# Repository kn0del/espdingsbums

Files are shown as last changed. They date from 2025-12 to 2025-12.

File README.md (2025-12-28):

# Zustand
--

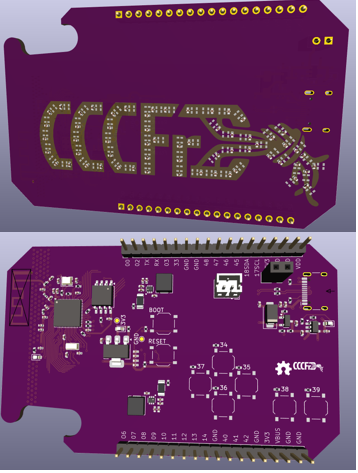
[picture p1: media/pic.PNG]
Board


**integrated bottle opener
one time use only**

Form Faktor: Kreditkarte/Perso?

- ESP32-S3 
- Antenne 
- Xtal 
- Voltage regulator 
- USB-C stecker 
- Li-Po Batteriencharger 
- Einige basic Tasten z.B RESET 
- Pin headers (vielleicht muss weg)
- LEDs an der Rückseite
- Mehrere Tasten (6)
- Flaschenöffner

# to-do liste
- ESD protection?
- Bildschirm an der Rückseite?
- Accelerometer?
- Noch was?

--

# Anleitung / Instructions

## DE

- Normallerweise sollte PlatformIO das Board als USB-Gerät erkennen.  
- Du brauchst keinen USB/UART-IC, z.B. CH340.  
- Der SoC hat diese Funktion bereits integriert.
- Die LEDs (XL-1615RGBC-2812B) sind eine Kleinformatversion der Standard WS2812B LEDs.Die nutzen einen digitalen Input-Pin (GPIO 21) und funktionieren wie jeder WS2812B LED strip. Theoretisch könntest du am Ende noch mehr einbauen, aber irgendwann wird dann zu viel Strom gebraucht.
- Die Reihenfolge der LEDs im Logo geht von oben nach unten und dann von links nach rechts auf einem quasi-Pixelraster, nicht von Buchstabe zu Buchstabe.
- LEDs verwenden ihre eigene 5V rail, die aktiviert werden muss, indem die Logik auf GPIO5 auf „high“ gesetzt wird.
- Die Reset- und Boot-Tasten haben eine bestimmte Funktion, aber die nummerierten Tasten sind nur dazu da, um programmiert zu werden. Sie sind standardmäßig alle auf „high“ gesetzt und werden durch Drücken der Taste auf „ground“ gesetzt.

**Wenn die Firmware kaputt geht:**  
- PlatformIO erkennt das Devboard nicht als USB-Gerät.  
- In diesem Fall: Halte die Boot-Taste (GPIO0) gedrückt und tippe auf Reset (EN).  
- Damit wird der Chip in den Download-Modus versetzt, und du kannst neue Firmware flashen.

---

## EN

- By default, PlatformIO should recognise the board as a USB device.  
- You don't need a USB/UART IC like CH340.  
- The SoC already has this function built in. 
- The LEDs (XL-1615RGBC-2812B) are a small package version of standard WS2812B LEDs, these use a digital input pin (GPIO 21) and work like any WS2812B strip. You can in theory add more at the end but at some point they would need too much current.
- The order of the LEDs in the logo go  top-down then left-right on a quasi pixel grid not letter by letter.
- LEDs use their own power rail that needs to be enabled by setting logic high on GPIO5
- Reset and Boot buttons have a specific function but the numbered ones are just there to be proggrammed. They are all pulled up by default and button press pulls them down to ground.

**If the firmware gets broken:**  
- PlatformIO does not recognise the devboard as a USB device.  
- In that case: hold the boot button (GPIO0) and tap reset (EN).  
- This will set the chip to download mode, and you can flash new firmware.

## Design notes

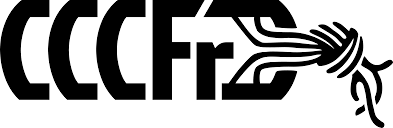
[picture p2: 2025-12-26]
media/Untitled.png

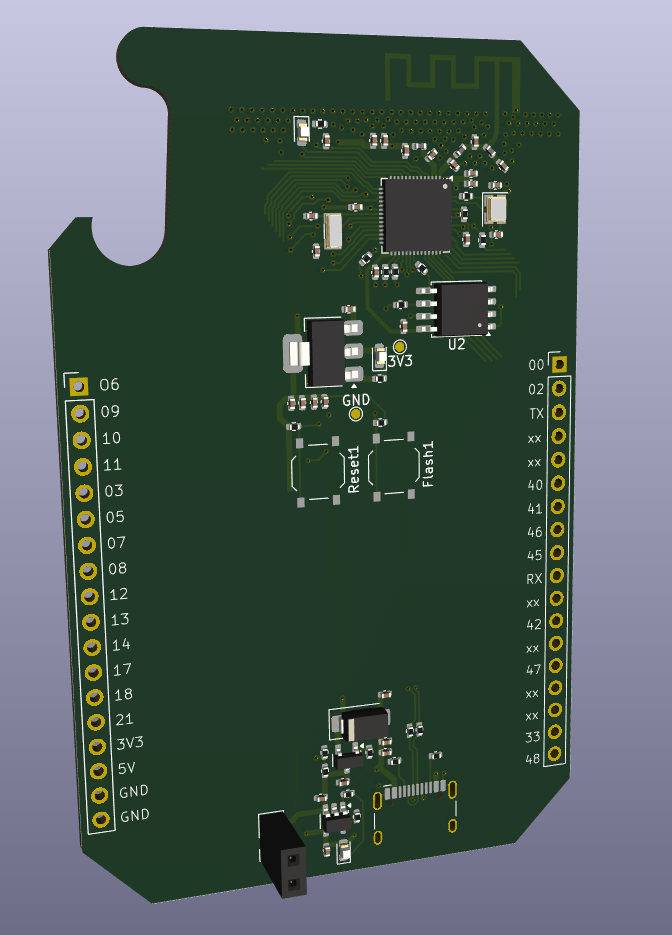
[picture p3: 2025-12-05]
media/pic - Copy.PNG

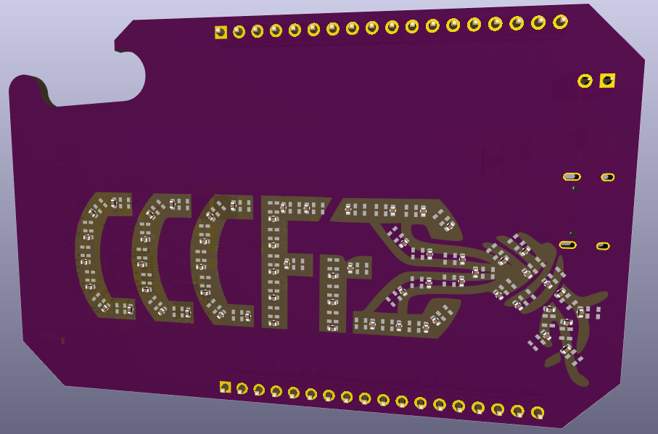
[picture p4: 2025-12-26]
media/pic - Copy (2).PNG

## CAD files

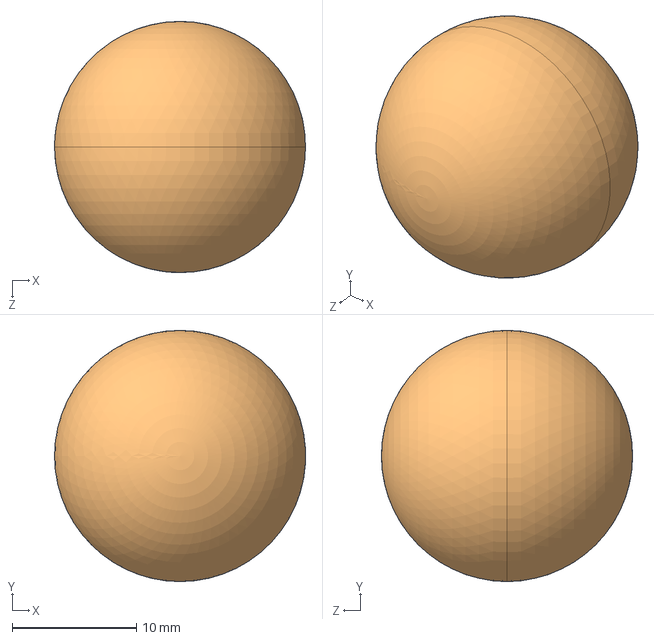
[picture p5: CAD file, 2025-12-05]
solid/original_esp32_module_antenna.STEP
20.2 x 20.3 x 20.3 mm

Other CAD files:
solid/original_esp32_module_antenna.SLDPRT

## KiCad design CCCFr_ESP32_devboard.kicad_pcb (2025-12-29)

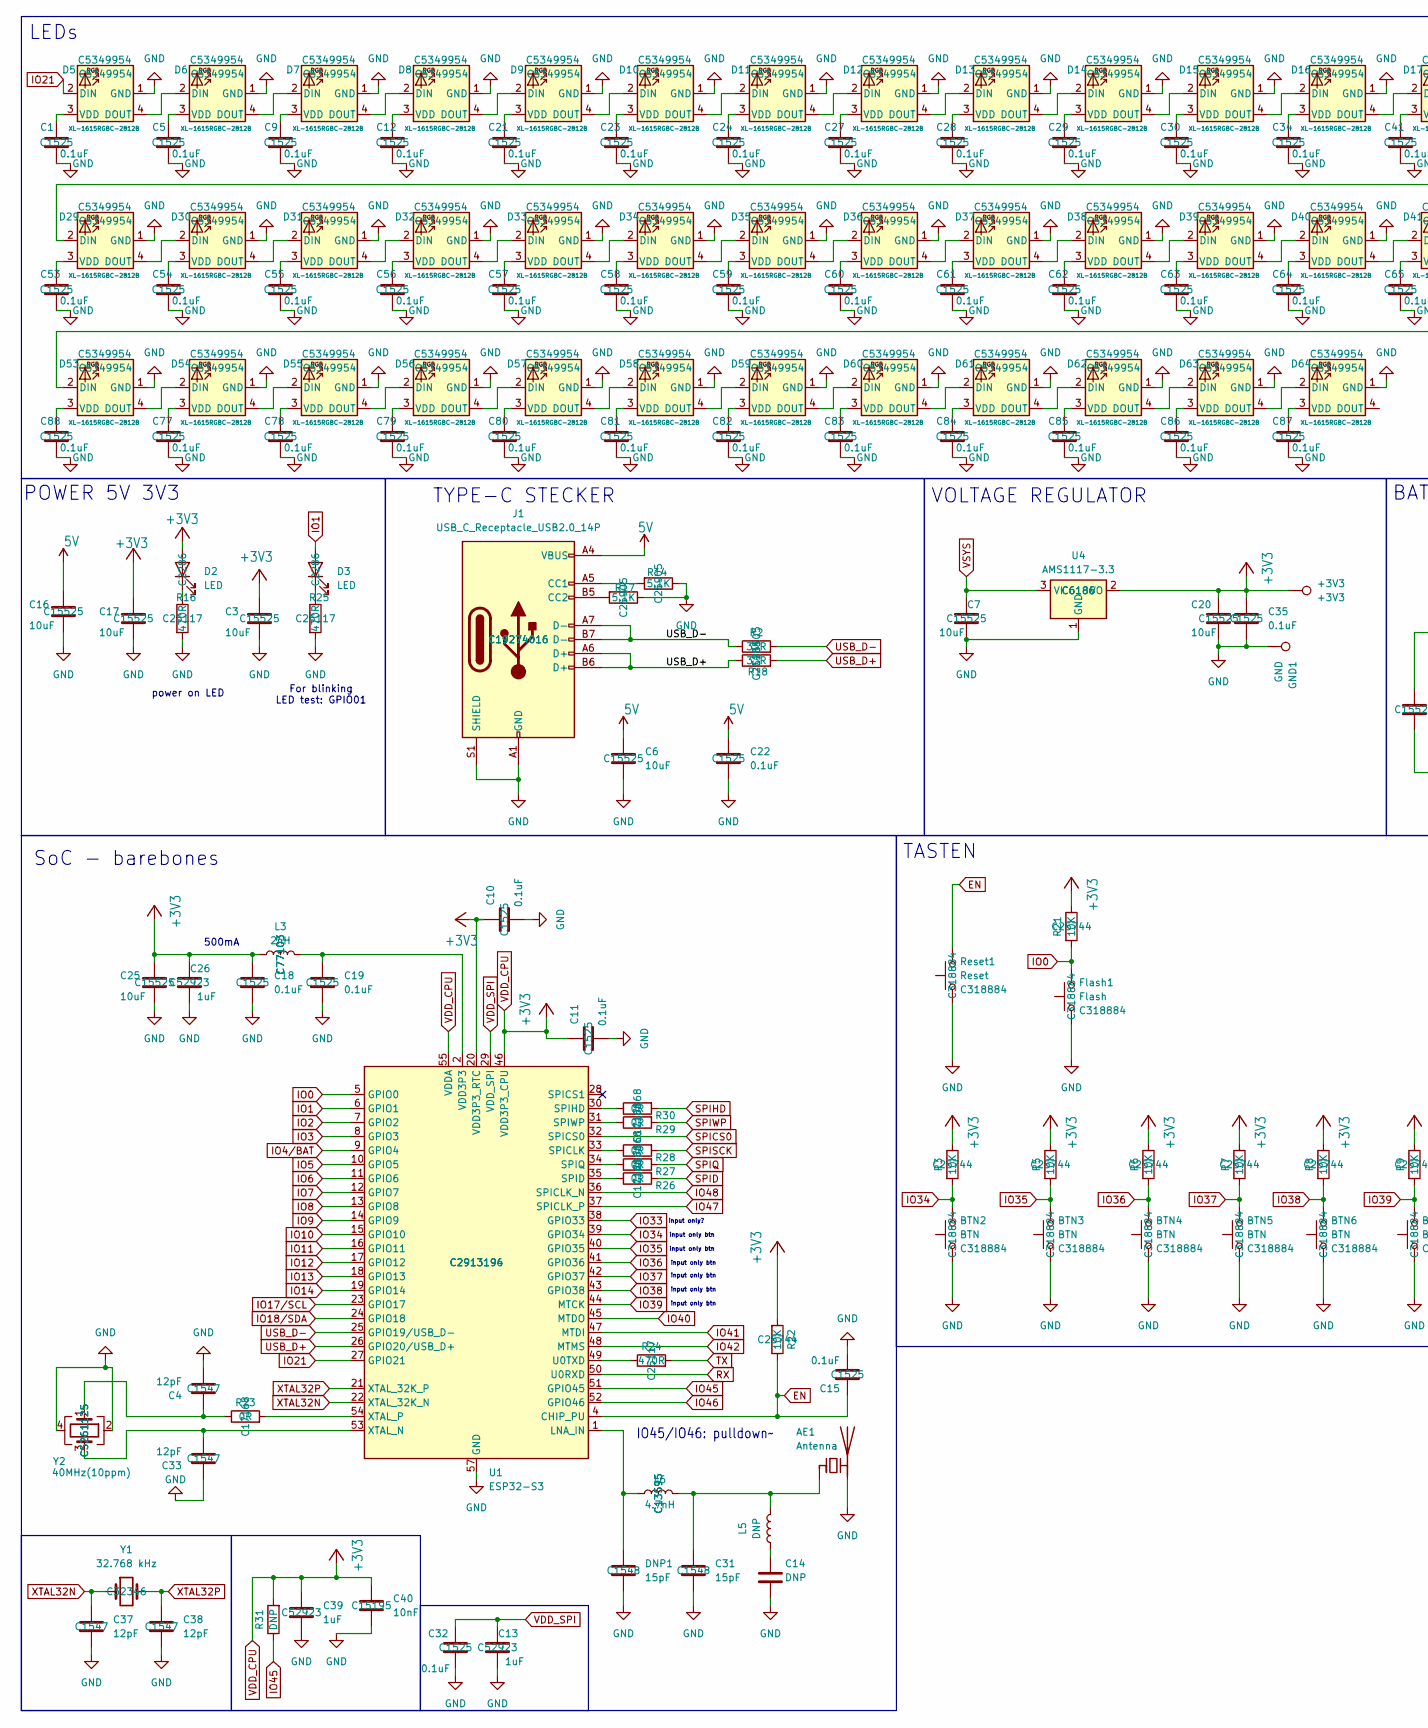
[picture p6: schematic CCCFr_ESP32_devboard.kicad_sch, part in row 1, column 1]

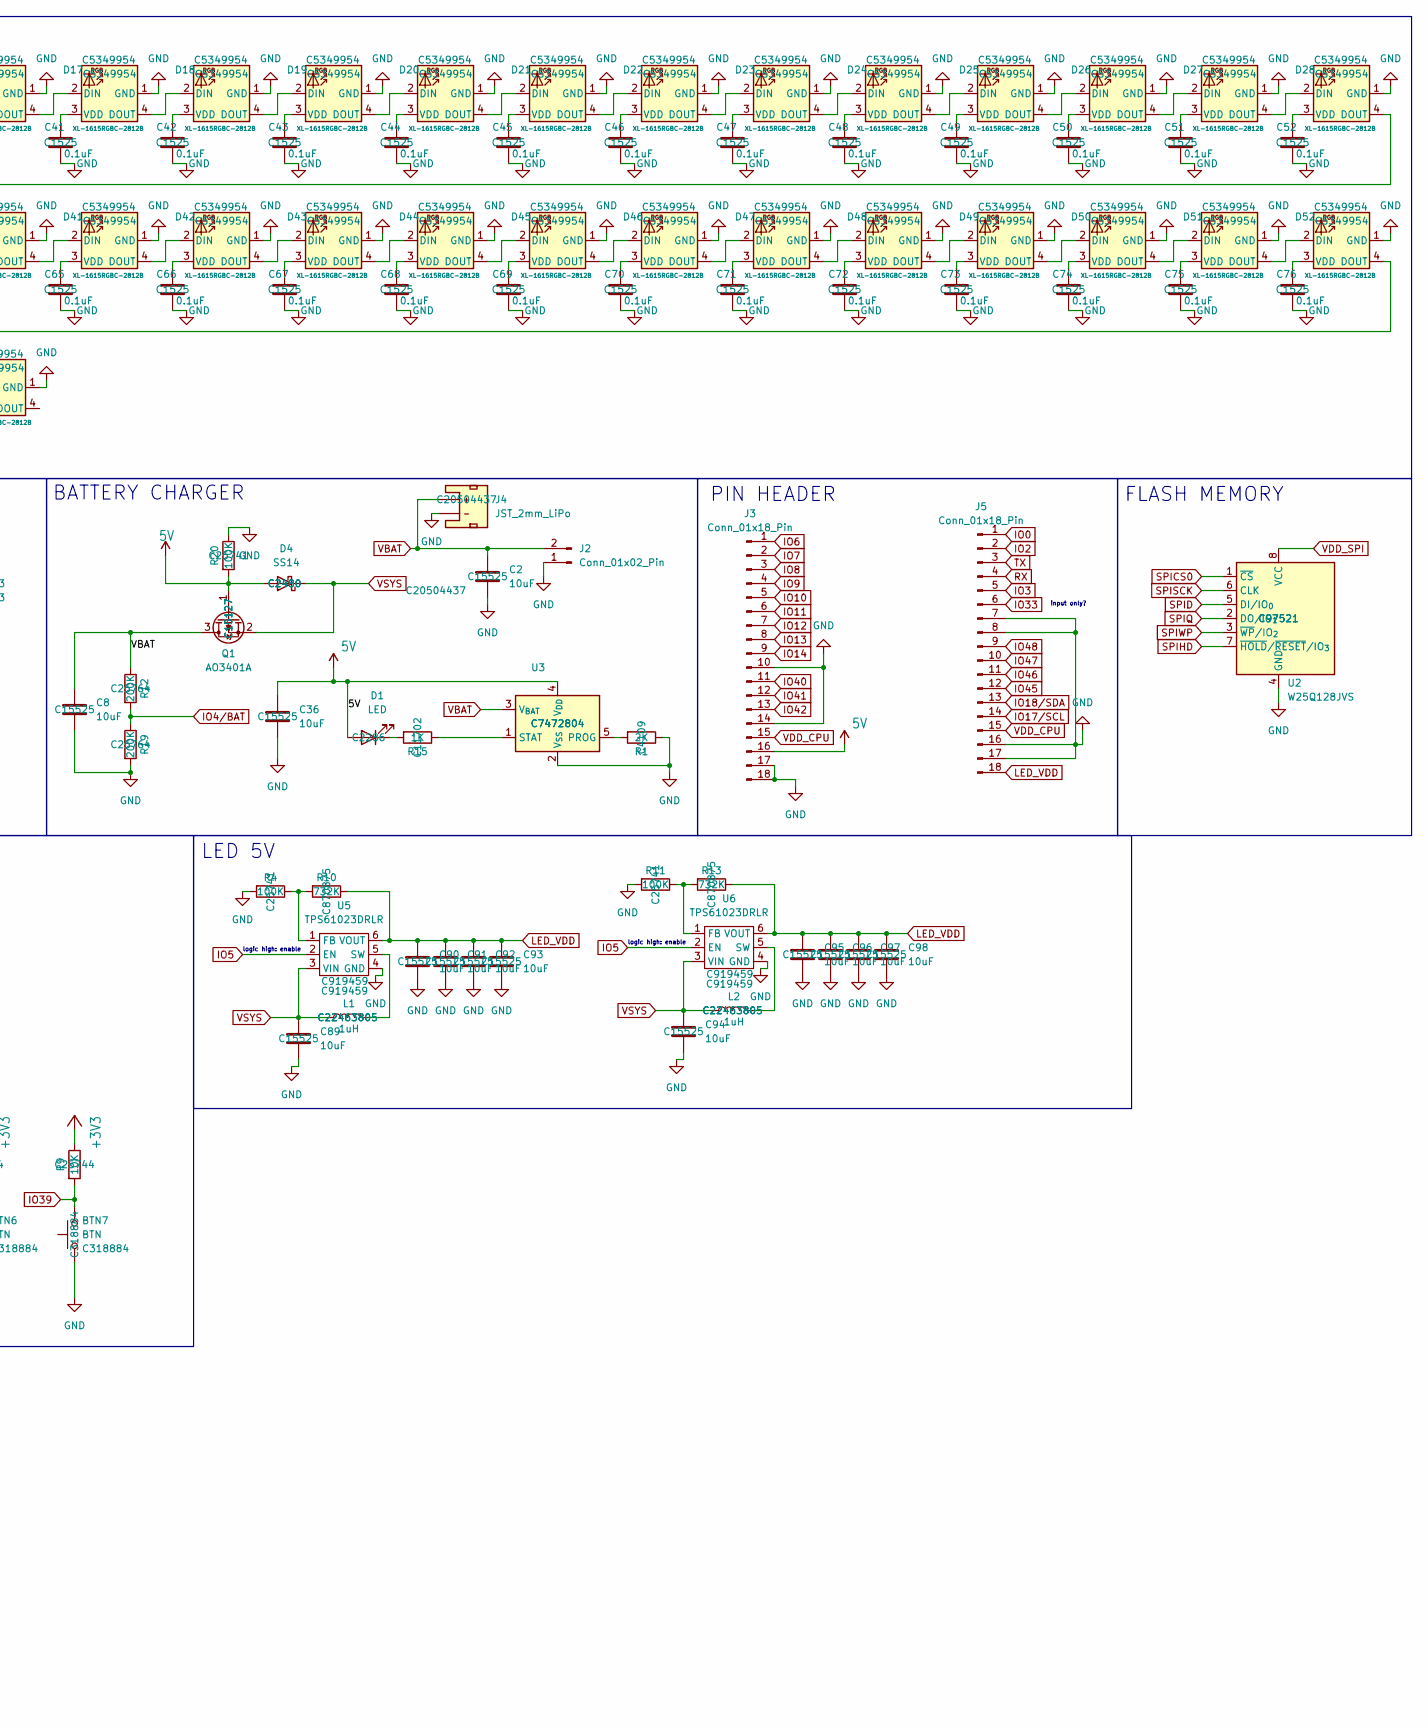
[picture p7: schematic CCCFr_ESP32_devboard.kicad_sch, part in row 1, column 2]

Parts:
+3V3: +3V3; TestPoint_Pad_D1.0mm
AE1: Antenna; Texas_SWRA117D_2.4GHz_Left
BTN2, BTN3, BTN4, BTN5, BTN6, BTN7: BTN; SW_Push_1P1T_XKB_TS-1187A; MNF PART NUMBER C318884; LCSC C318884
C1, C5, C9, C10, C11, C12, C15, C18, C19, C21, C22, C23, C24, C27, C28, C29, C30, C32, C34, C35, C41, C42, C43, C44, C45, C46, C47, C48, C49, C50, C51, C52, C53, C54, C55, C56, C57, C58, C59, C60, C61, C62, C63, C64, C65, C66, C67, C68, C69, C70, C71, C72, C73, C74, C75, C76, C77, C78, C79, C80, C81, C82, C83, C84, C85, C86, C87, C88: 0.1uF; C_0402_1005Metric; MNF PART NUMBER C1525; LCSC C1525
C2, C3, C6, C7, C8, C16, C17, C20, C25, C36, C89, C90, C91, C92, C93, C94, C95, C96, C97, C98: 10uF; C_0402_1005Metric; MNF PART NUMBER C15525; LCSC C15525
C4, C33, C37, C38: 12pF; C_0402_1005Metric; MNF PART NUMBER C1547; LCSC C1547
C13, C26, C39: 1uF; C_0402_1005Metric; MNF PART NUMBER C52923; LCSC C52923
C14: DNP; C_0402_1005Metric
C31: 15pF; C_0402_1005Metric; MNF PART NUMBER C1548; LCSC C1548
C40: 10nF; C_0402_1005Metric; MNF PART NUMBER C15195; LCSC C15195
D1, D2, D3: LED; LED_0603_1608Metric; MNF PART NUMBER C2286; LCSC C2286
D4: SS14; D_SMA; MNF PART NUMBER C2480; LCSC C2480
D5, D6, D7, D8, D9, D10, D11, D12, D13, D14, D15, D16, D17, D18, D19, D20, D21, D22, D23, D24, D25, D26, D27, D28, D29, D30, D31, D32, D33, D34, D35, D36, D37, D38, D39, D40, D41, D42, D43, D44, D45, D46, D47, D48, D49, D50, D51, D52, D53, D54, D55, D56, D57, D58, D59, D60, D61, D62, D63, D64: XL-1615RGBC-2812B; MNF PART NUMBER C5349954; LCSC C5349954
DNP1: 15pF; C_0402_1005Metric; MNF PART NUMBER C1548; LCSC C1548
Flash1: Flash; SW_Push_1P1T_XKB_TS-1187A; MNF PART NUMBER C318884; LCSC C318884
GND1: GND; TestPoint_Pad_D1.0mm
J1: USB_C_Receptacle_USB2.0_14P; USB_C_Receptacle_HCTL_HC-TYPE-C-16P-01A; MNF PART NUMBER C19274016; LCSC C19274016
J2: Conn_01x02_Pin; PinSocket_1x02_P2.54mm_Vertical
J3, J5: Conn_01x18_Pin; PinHeader_1x18_P2.54mm_Vertical
J4: JST_2mm_LiPo; JST_PH_B2B-PH-K_1x02_P2.00mm_Vertical; MNF PART NUMBER C20504437; LCSC C20504437
L1, L2: 1uH; L_TechFuse_SL0420; MNF PART NUMBER C22463805; LCSC C22463805
L3: 2nH; L_0402_1005Metric; MNF PART NUMBER C77103; LCSC C77103
L5: DNP; L_0402_1005Metric
L6: 4.7nH; L_0402_1005Metric; MNF PART NUMBER C13595; LCSC C13595
Q1: AO3401A; SOT-23; MNF PART NUMBER C15127; LCSC C15127
R1: 2K; R_0402_1005Metric; MNF PART NUMBER C4109; LCSC C4109
R2, R18: 33R; R_0402_1005Metric; MNF PART NUMBER C25105; LCSC C25105
R3, R5, R6, R7, R8, R9, R21, R22: 10K; R_0402_1005Metric; MNF PART NUMBER C25744; LCSC C25744
R4, R11, R20: 100K; R_0402_1005Metric; MNF PART NUMBER C25741; LCSC C25741
R10, R13: 732K; R_1206_3216Metric; MNF PART NUMBER C870875; LCSC C870875
R12, R19: 200K; R_0402_1005Metric; MNF PART NUMBER C25764; LCSC C25764
R14, R17: 5.1K; R_0402_1005Metric; MNF PART NUMBER C25905; LCSC C25905
R15: 1K; R_0402_1005Metric; MNF PART NUMBER C11702; LCSC C11702
R16, R24, R25: 470R; R_0402_1005Metric; MNF PART NUMBER C25117; LCSC C25117
R23, R26, R27, R28, R29, R30: 0R; R_0402_1005Metric; MNF PART NUMBER C17168; LCSC C17168
R31: DNP; R_0402_1005Metric
Reset1: Reset; SW_Push_1P1T_XKB_TS-1187A; MNF PART NUMBER C318884; LCSC C318884
U1: ESP32-S3; QFN-56-1EP_7x7mm_P0.4mm_EP4x4mm; MNF PART NUMBER C2913196; LCSC C2913194
U2: W25Q128JVS; SOIC-8_5.3x5.3mm_P1.27mm; MNF PART NUMBER C97521; LCSC C97521
U3: MCP73831-2-OT; SOT-23-5; MNF PART NUMBER C7472804; LCSC C7472804
U4: AMS1117-3.3; SOT-223-3_TabPin2; MNF PART NUMBER C6186; LCSC C6186
U5, U6: TPS61023DRLR; SOT-563; MNF PART NUMBER C919459; LCSC C919459
Y1: 32.768 kHz; Crystal_SMD_3215-2Pin_3.2x1.5mm; MNF PART NUMBER C32346; LCSC C32346
Y2: 40MHz(10ppm); Crystal_SMD_2520-4Pin_2.5x2.0mm; MNF PART NUMBER C5261125; LCSC C5261125

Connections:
5V: C6.1, C16.1, C22.1, C36.1, D1.2 (A), D4.2 (A), J1.A4 (VBUS), J1.A9 (VBUS), J1.B4 (VBUS), J1.B9 (VBUS), J3.16, Q1.1 (G), R20.2, U3.4 (V_{DD})
EN: C15.1, R22.1, Reset1.2, U1.4 (CHIP_PU)
GND: AE1.2 (PCB_Trace), BTN2.1, BTN3.1, BTN4.1, BTN5.1, BTN6.1, BTN7.1, C1.2, C2.2, C3.2, C4.2, C5.2, C6.2, C7.2, C8.2, C9.2, C10.2, C11.2, C12.2, C13.2, C14.2, C15.2, C16.2, C17.2, C18.2, C19.2, C20.2, C21.2, C22.2, C23.2, C24.2, C25.2, C26.2, C27.2, C28.2, C29.2, C30.2, C31.2, C32.2, C33.1, C34.2, C35.2, C36.2, C37.2, C38.2, C39.2, C40.2, C41.2, C42.2, C43.2, C44.2, C45.2, C46.2, C47.2, C48.2, C49.2, C50.2, C51.2, C52.2, C53.2, C54.2, C55.2, C56.2, C57.2, C58.2, C59.2, C60.2, C61.2, C62.2, C63.2, C64.2, C65.2, C66.2, C67.2, C68.2, C69.2, C70.2, C71.2, C72.2, C73.2, C74.2, C75.2, C76.2, C77.2, C78.2, C79.2, C80.2, C81.2, C82.2, C83.2, C84.2, C85.2, C86.2, C87.2, C88.2, C89.2, C90.2, C91.2, C92.2, C93.2, C94.2, C95.2, C96.2, C97.2, C98.2, D5.1 (GND), D6.1 (GND), D7.1 (GND), D8.1 (GND), D9.1 (GND), D10.1 (GND), D11.1 (GND), D12.1 (GND), D13.1 (GND), D14.1 (GND), D15.1 (GND), D16.1 (GND), D17.1 (GND), D18.1 (GND), D19.1 (GND), D20.1 (GND), D21.1 (GND), D22.1 (GND), D23.1 (GND), D24.1 (GND), D25.1 (GND), D26.1 (GND), D27.1 (GND), D28.1 (GND), D29.1 (GND), D30.1 (GND), D31.1 (GND), D32.1 (GND), D33.1 (GND), D34.1 (GND), D35.1 (GND), D36.1 (GND), D37.1 (GND), D38.1 (GND), D39.1 (GND), D40.1 (GND), D41.1 (GND), D42.1 (GND), D43.1 (GND), D44.1 (GND), D45.1 (GND), D46.1 (GND), D47.1 (GND), D48.1 (GND), D49.1 (GND), D50.1 (GND), D51.1 (GND), D52.1 (GND), D53.1 (GND), D54.1 (GND), D55.1 (GND), D56.1 (GND), D57.1 (GND), D58.1 (GND), D59.1 (GND), D60.1 (GND), D61.1 (GND), D62.1 (GND), D63.1 (GND), D64.1 (GND), DNP1.2, Flash1.1, GND1.1, J1.A1 (GND), J1.A12 (GND), J1.B1 (GND), J1.B12 (GND), J1.S1 (SHIELD), J2.1, J3.10, J3.14, J3.17, J3.18, J4.1 (-), J5.7, J5.8, J5.16, J5.17, R1.1, R4.2, R11.2, R14.1, R16.2, R17.1, R19.2, R20.1, R25.2, Reset1.1, U1.57 (GND), U2.4 (GND), U3.2 (V_{SS}), U4.1 (GND), U5.4 (GND), U6.4 (GND), Y2.2, Y2.4
IO0: Flash1.2, J5.1, R21.2, U1.5 (GPIO0)
IO1: D3.2 (A), U1.6 (GPIO1)
IO2: J5.2, U1.7 (GPIO2)
IO3: J5.5, U1.8 (GPIO3)
IO4/BAT: R12.2, R19.1, U1.9 (GPIO4)
IO5: U1.10 (GPIO5), U5.2 (EN), U6.2 (EN)
IO6: J3.1, U1.11 (GPIO6)
IO7: J3.2, U1.12 (GPIO7)
IO8: J3.3, U1.13 (GPIO8)
IO9: J3.4, U1.14 (GPIO9)
IO10: J3.5, U1.15 (GPIO10)
IO11: J3.6, U1.16 (GPIO11)
IO12: J3.7, U1.17 (GPIO12)
IO13: J3.8, U1.18 (GPIO13)
IO14: J3.9, U1.19 (GPIO14)
IO17/SCL: J5.14, U1.23 (GPIO17)
IO18/SDA: J5.13, U1.24 (GPIO18)
IO21: D5.2 (DIN), U1.27 (GPIO21)
IO33: J5.6, U1.38 (GPIO33)
IO34: BTN2.2, R3.2, U1.39 (GPIO34)
IO35: BTN3.2, R5.2, U1.40 (GPIO35)
IO36: BTN4.2, R6.2, U1.41 (GPIO36)
IO37: BTN5.2, R7.2, U1.42 (GPIO37)
IO38: BTN6.2, R8.2, U1.43 (GPIO38)
IO39: BTN7.2, R9.2, U1.44 (MTCK)
IO40: J3.11, U1.45 (MTDO)
IO41: J3.12, U1.47 (MTDI)
IO42: J3.13, U1.48 (MTMS)
IO45: J5.12, R31.1, U1.51 (GPIO45)
IO46: J5.11, U1.52 (GPIO46)
IO47: J5.10, U1.37 (SPICLK_P)
IO48: J5.9, U1.36 (SPICLK_N)
LED_VDD: C90.1, C91.1, C92.1, C93.1, C95.1, C96.1, C97.1, C98.1, J5.18, R10.1, R13.1, U5.6 (VOUT), U6.6 (VOUT)
unnamed: AE1.1 (FEED), C31.1, L5.2, L6.2
unnamed: C4.1, R23.1, Y2.1
unnamed: C14.1, L5.1
unnamed: C19.1, L3.2, U1.2 (VDD3P3), U1.3 (VDD3P3)
unnamed: D1.1 (K), R15.2
unnamed: D2.1 (K), R16.1
unnamed: D3.1 (K), R25.1
unnamed: D5.4 (DOUT), D6.2 (DIN)
unnamed: C1.1, D5.3 (VDD)
unnamed: D6.4 (DOUT), D7.2 (DIN)
unnamed: C5.1, D6.3 (VDD)
unnamed: D7.4 (DOUT), D8.2 (DIN)
unnamed: C9.1, D7.3 (VDD)
unnamed: D8.4 (DOUT), D9.2 (DIN)
unnamed: C12.1, D8.3 (VDD)
unnamed: C21.1, D9.3 (VDD)
unnamed: D9.4 (DOUT), D10.2 (DIN)
unnamed: D10.4 (DOUT), D11.2 (DIN)
unnamed: C23.1, D10.3 (VDD)
unnamed: D11.4 (DOUT), D12.2 (DIN)
unnamed: C24.1, D11.3 (VDD)
unnamed: D12.4 (DOUT), D13.2 (DIN)
unnamed: C27.1, D12.3 (VDD)
unnamed: D13.4 (DOUT), D14.2 (DIN)
unnamed: C28.1, D13.3 (VDD)
unnamed: D14.4 (DOUT), D15.2 (DIN)
unnamed: C29.1, D14.3 (VDD)
unnamed: D15.4 (DOUT), D16.2 (DIN)
unnamed: C30.1, D15.3 (VDD)
unnamed: D16.4 (DOUT), D17.2 (DIN)
unnamed: C34.1, D16.3 (VDD)
unnamed: D17.4 (DOUT), D18.2 (DIN)
unnamed: C41.1, D17.3 (VDD)
unnamed: D18.4 (DOUT), D19.2 (DIN)
unnamed: C42.1, D18.3 (VDD)
unnamed: D19.4 (DOUT), D20.2 (DIN)
unnamed: C43.1, D19.3 (VDD)
unnamed: D20.4 (DOUT), D21.2 (DIN)
unnamed: C44.1, D20.3 (VDD)
unnamed: D21.4 (DOUT), D22.2 (DIN)
unnamed: C45.1, D21.3 (VDD)
unnamed: D22.4 (DOUT), D23.2 (DIN)
unnamed: C46.1, D22.3 (VDD)
unnamed: D23.4 (DOUT), D24.2 (DIN)
unnamed: C47.1, D23.3 (VDD)
unnamed: D24.4 (DOUT), D25.2 (DIN)
unnamed: C48.1, D24.3 (VDD)
unnamed: D25.4 (DOUT), D26.2 (DIN)
unnamed: C49.1, D25.3 (VDD)
unnamed: D26.4 (DOUT), D27.2 (DIN)
unnamed: C50.1, D26.3 (VDD)
unnamed: D27.4 (DOUT), D28.2 (DIN)
unnamed: C51.1, D27.3 (VDD)
unnamed: D28.4 (DOUT), D29.2 (DIN)
unnamed: C52.1, D28.3 (VDD)
unnamed: D29.4 (DOUT), D30.2 (DIN)
unnamed: C53.1, D29.3 (VDD)
unnamed: D30.4 (DOUT), D31.2 (DIN)
unnamed: C54.1, D30.3 (VDD)
unnamed: D31.4 (DOUT), D32.2 (DIN)
unnamed: C55.1, D31.3 (VDD)
unnamed: D32.4 (DOUT), D33.2 (DIN)
unnamed: C56.1, D32.3 (VDD)
unnamed: D33.4 (DOUT), D34.2 (DIN)
unnamed: C57.1, D33.3 (VDD)
unnamed: D34.4 (DOUT), D35.2 (DIN)
unnamed: C58.1, D34.3 (VDD)
unnamed: D35.4 (DOUT), D36.2 (DIN)
unnamed: C59.1, D35.3 (VDD)
unnamed: D36.4 (DOUT), D37.2 (DIN)
unnamed: C60.1, D36.3 (VDD)
unnamed: D37.4 (DOUT), D38.2 (DIN)
unnamed: C61.1, D37.3 (VDD)
unnamed: D38.4 (DOUT), D39.2 (DIN)
unnamed: C62.1, D38.3 (VDD)
unnamed: D39.4 (DOUT), D40.2 (DIN)
unnamed: C63.1, D39.3 (VDD)
unnamed: D40.4 (DOUT), D41.2 (DIN)
unnamed: C64.1, D40.3 (VDD)
unnamed: D41.4 (DOUT), D42.2 (DIN)
unnamed: C65.1, D41.3 (VDD)
unnamed: D42.4 (DOUT), D43.2 (DIN)
unnamed: C66.1, D42.3 (VDD)
unnamed: D43.4 (DOUT), D44.2 (DIN)
unnamed: C67.1, D43.3 (VDD)
unnamed: D44.4 (DOUT), D45.2 (DIN)
unnamed: C68.1, D44.3 (VDD)
unnamed: D45.4 (DOUT), D46.2 (DIN)
unnamed: C69.1, D45.3 (VDD)
unnamed: D46.4 (DOUT), D47.2 (DIN)
unnamed: C70.1, D46.3 (VDD)
unnamed: D47.4 (DOUT), D48.2 (DIN)
unnamed: C71.1, D47.3 (VDD)
unnamed: D48.4 (DOUT), D49.2 (DIN)
unnamed: C72.1, D48.3 (VDD)
unnamed: D49.4 (DOUT), D50.2 (DIN)
unnamed: C73.1, D49.3 (VDD)
unnamed: D50.4 (DOUT), D51.2 (DIN)
unnamed: C74.1, D50.3 (VDD)
unnamed: D51.4 (DOUT), D52.2 (DIN)
unnamed: C75.1, D51.3 (VDD)
unnamed: D52.4 (DOUT), D53.2 (DIN)
unnamed: C76.1, D52.3 (VDD)
unnamed: D53.4 (DOUT), D54.2 (DIN)
unnamed: C88.1, D53.3 (VDD)
unnamed: D54.4 (DOUT), D55.2 (DIN)
unnamed: C77.1, D54.3 (VDD)
unnamed: D55.4 (DOUT), D56.2 (DIN)
unnamed: C78.1, D55.3 (VDD)
unnamed: D56.4 (DOUT), D57.2 (DIN)
unnamed: C79.1, D56.3 (VDD)
unnamed: D57.4 (DOUT), D58.2 (DIN)
unnamed: C80.1, D57.3 (VDD)
unnamed: D58.4 (DOUT), D59.2 (DIN)
unnamed: C81.1, D58.3 (VDD)
unnamed: D59.4 (DOUT), D60.2 (DIN)
unnamed: C82.1, D59.3 (VDD)
unnamed: D60.4 (DOUT), D61.2 (DIN)
unnamed: C83.1, D60.3 (VDD)
unnamed: D61.4 (DOUT), D62.2 (DIN)
unnamed: C84.1, D61.3 (VDD)
unnamed: D62.4 (DOUT), D63.2 (DIN)
unnamed: C85.1, D62.3 (VDD)
unnamed: D63.4 (DOUT), D64.2 (DIN)
unnamed: C86.1, D63.3 (VDD)
unnamed: C87.1, D64.3 (VDD)
unnamed: J1.A5 (CC1), R14.2
unnamed: J1.B5 (CC2), R17.2
unnamed: DNP1.1, L6.1, U1.1 (LNA_IN)
unnamed: R28.1, U1.33 (SPICLK)
unnamed: R26.1, U1.35 (SPID)
unnamed: R30.1, U1.30 (SPIHD)
unnamed: R27.1, U1.34 (SPIQ)
unnamed: R29.1, U1.31 (SPIWP)
unnamed: R24.1, U1.49 (U0TXD)
unnamed: C33.2, U1.53 (XTAL_N), Y2.3
unnamed: R23.2, U1.54 (XTAL_P)
unnamed: R1.2, U3.5 (PROG)
unnamed: R15.1, U3.1 (STAT)
unnamed: R4.1, R10.2, U5.1 (FB)
unnamed: L1.2, U5.5 (SW)
unnamed: R11.1, R13.2, U6.1 (FB)
unnamed: L2.2, U6.5 (SW)
RX: J5.4, U1.50 (U0RXD)
SPICS0: U1.32 (SPICS0), U2.1 (~CS)
SPID: R26.2, U2.5 (DI/IO_{0})
SPIHD: R30.2, U2.7 (~HOLD/~RESET/IO_{3})
SPIQ: R27.2, U2.2 (DO/IO_{1})
SPISCK: R28.2, U2.6 (CLK)
SPIWP: R29.2, U2.3 (~WP/IO_{2})
TX: J5.3, R24.2
USB_D+: J1.A6 (D+), J1.B6 (D+), R18.1, R18.2, U1.26 (GPIO20/USB_D+)
USB_D-: J1.A7 (D-), J1.B7 (D-), R2.1, R2.2, U1.25 (GPIO19/USB_D-)
VBAT: C2.1, C8.1, J2.2, J4.2 (+), Q1.3 (D), R12.1, U3.3 (V_{BAT})
VDD_CPU: +3V3.1, C3.1, C10.1, C11.1, C17.1, C18.1, C20.1, C25.1, C26.1, C35.1, C39.1, C40.1, D2.2 (A), J3.15, J5.15, L3.1, R3.1, R5.1, R6.1, R7.1, R8.1, R9.1, R21.1, R22.2, R31.2, U1.20 (VDD3P3_RTC), U1.46 (VDD3P3_CPU), U1.55 (VDDA), U1.56 (VDDA), U4.2 (VO)
VDD_SPI: C13.1, C32.1, U1.29 (VDD_SPI), U2.8 (VCC)
VSYS: C7.1, C89.1, C94.1, D4.1 (K), L1.1, L2.1, Q1.2 (S), U4.3 (VI), U5.3 (VIN), U6.3 (VIN)
XTAL32N: C37.1, U1.22 (XTAL_32K_N), Y1.1
XTAL32P: C38.1, U1.21 (XTAL_32K_P), Y1.2

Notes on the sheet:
BATTERY CHARGER
VOLTAGE REGULATOR
input only btn
power on LED
500mA
LEDs
SoC - barebones
PIN HEADER
FLASH MEMORY
logic high: enable
input only?
LED 5V
TASTEN
For blinking LED test: GPIO01
POWER 5V 3V3
IO45/IO46: pulldown~~{}
TYPE-C STECKER

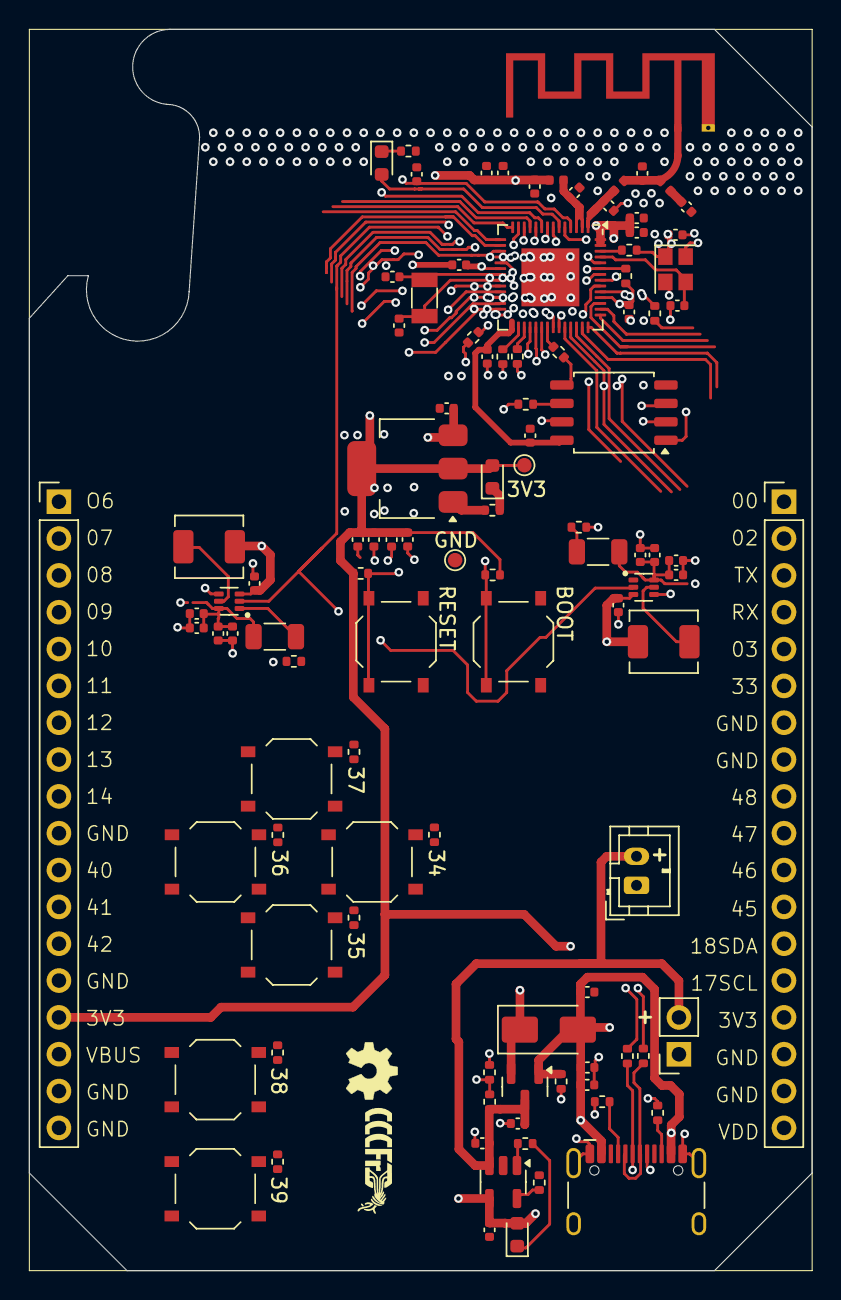
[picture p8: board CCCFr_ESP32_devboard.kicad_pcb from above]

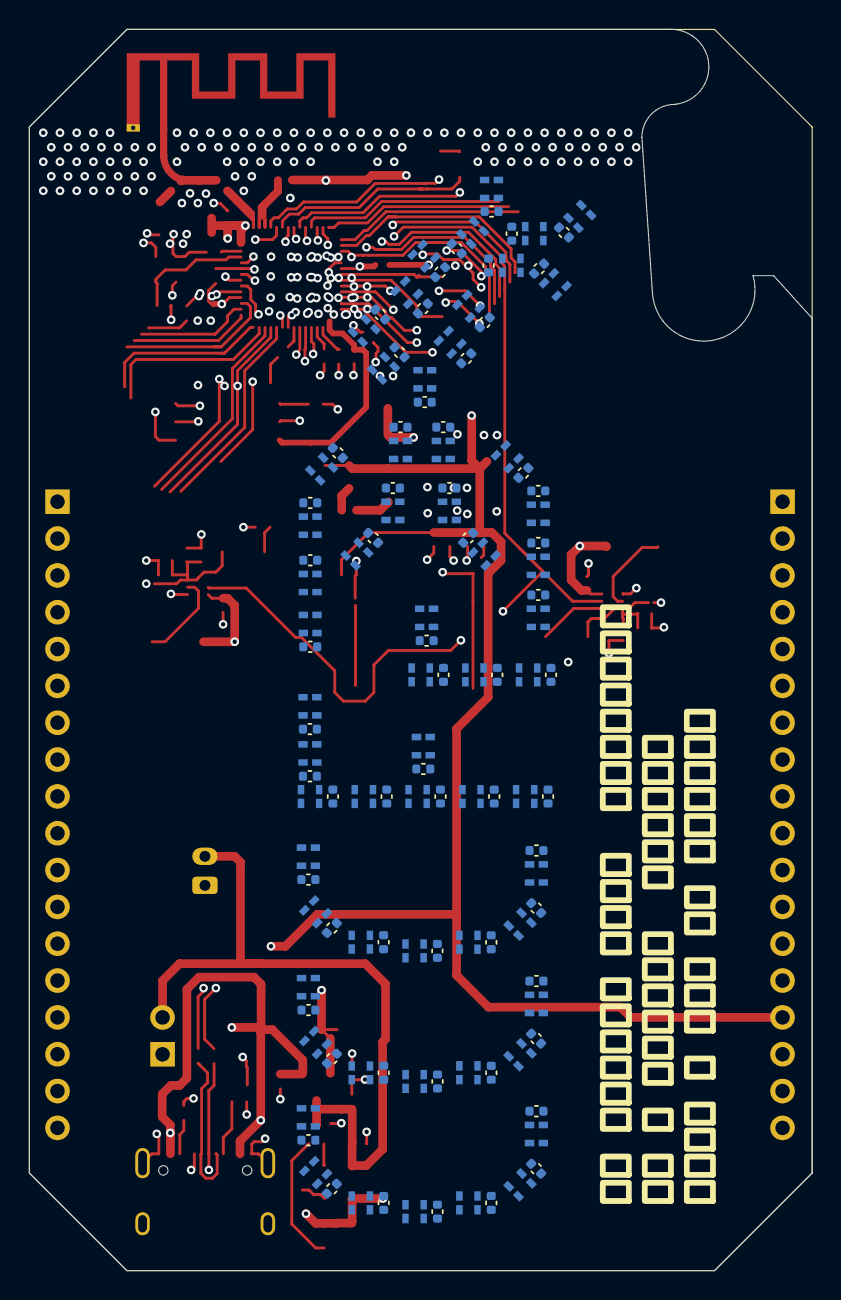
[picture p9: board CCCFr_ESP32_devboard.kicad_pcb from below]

Board: 4 copper layers, 54.0 x 85.6 mm, 225 parts (120 on the bottom side), 195 nets.

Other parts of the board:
Ref**: Val**; OSHW_Logo_4mm

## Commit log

2025-12-02 added extra memory
    [CCCFr_ESP32_devboard.kicad_pcb, CCCFr_ESP32_devboard.kicad_sch]
2025-12-04 integrated bottle opener
    [CCCFr_ESP32_devboard.kicad_pcb, CCCFr_ESP32_devboard.kicad_sch, original_esp32_module_antenna.SLDPRT]
2025-12-05 switchewd to kicad 9
    [CCCFr_ESP32_devboard.kicad_pcb, CCCFr_ESP32_devboard.kicad_sch, original_esp32_module_antenna.SLDPRT]
2025-12-05 added antenna model WIP
    [original_esp32_module_antenna.SLDPRT, original_esp32_module_antenna.STEP]
2025-12-26 Added 60 pieces of 2812B in the shape of CCCFr
    [CCCFr_ESP32_devboard.kicad_pcb, CCCFr_ESP32_devboard.kicad_sch]
2025-12-26 Added buttons
    [CCCFr_ESP32_devboard.kicad_pcb, CCCFr_ESP32_devboard.kicad_sch]
2025-12-28 rearrandged footprints
    [CCCFr_ESP32_devboard.kicad_pcb, CCCFr_ESP32_devboard.kicad_sch]
2025-12-28 Added JST plug for battery
    [CCCFr_ESP32_devboard.kicad_pcb, CCCFr_ESP32_devboard.kicad_sch]
2025-12-28 routed a bit
    [CCCFr_ESP32_devboard.kicad_pcb]
2025-12-29 added some instructions
    [CCCFr_ESP32_devboard.kicad_pcb]
